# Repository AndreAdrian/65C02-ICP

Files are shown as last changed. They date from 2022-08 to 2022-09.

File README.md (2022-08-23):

# 65C02-ICP
65C02 single board computer with in-circuit-programming

The 65C02-ICP is my little 65C02 computer. I have 32kByte RAM, 8kByte EEPROM, a (buggy) WDC 65C51N ACIA RS232 interface and 7.3728MHz clock. Like [Ben Eater](https://eater.net/6502) I use a single 74HC00 for glue logic. And I have in-circuit-programming. This is the big difference to other 6502 single board computers. I need no EEPROM programmer. I have two CP2102 USB-to-UART bridges. One I use to program the EEPROM in-circuit, the other I use to communicate between my MS-Windows computer via [TeraTerm](https://ttssh2.osdn.jp/index.html.en) terminal emulator program and my 65C02 with 38400bps.

My monitor program - mon7.asm - uses RTS/CTS hardware handshake, interrupt driven receive and a 256 Byte receive buffer to work around the 65C51N TDRE (transmit data register empty) bug. I assume my monitor is compatible to other 6551. The monitor has three commands. Download bytes into memory with the : command, examine memory with the p command and execute a program with the r command. If the program executes a BRK opcode, the monitor prints a trace. That is the contents of the Y, X, A, P registers and the PC plus two more bytes on the stack. The monitor machine code length is 320Bytes. The mon7 api is:
```
monbyte = $0    ; 1 byte used by getbyte/putbyte
monword = $1    ; 2 bytes used by getword/putword
monwrptr= $3    ; 2 bytes buf write pointer used by getc
monrdptr= $5    ; 2 bytes buf read pointer used by getc
monbfcnt= $7    ; 1 byte buf count used by getc
montmpy = $8    ; 1 byte tmp used by getc
nmihook = $7EFD ; 3 bytes used by mon
monbuf  = $7F00 ; 256 bytes buf used by getc
getc    = $FF7E ; jsr console (65C51) input, out: a=char
echoc   = $FF81 ; jsr console input with echo, out: a=char
putc    = $FF84 ; jsr console output, in: a=char
asc2hex = $FF96 ; jsr convert ASCII to hex, in: a=ascii, out: a=hex
hex2asc = $FFA6 ; jsr convert hex to ASCII, in: a=hex, return a=ascii
getbyte = $FFB0 ; jsr input 2 Hex digits in ASCII, out: a=byte
putbyte = $FFC5 ; jsr output 2 Hex digits as ASCII, in: a=byte
getword = $FFDB ; jsr input 4 Hex digits in ASCII, out: monword=word
putword = $FFE6 ; jsr output 4 Hex digits as ASCII, in: monword=word
putcrlf = $FFF0 ; jsr output Carrige Return, Line Feed
```
The second program is int.asm. This is a 16Bit integer package with some basic ASCIIZ string subroutines. For subroutine arguments (parameters) I use register A=low byte, X=high byte. Or you can place the parameters into "well known" zero page variables and call the subroutines. The 16Bit integer package is fast. I use the fastest multiplication and division subroutines from the net and I use my own fast integer to decimal conversation subroutine. The same int2dec idea I used in the 1980s for my Z80 32Bit integer package. The int api is:
```
intsign = $9   ; 1 byte used by dec2int, intdiv, i32div
intarg  = $A   ; 2 bytes 16bit argument
intacc  = $C   ; 4 bytes 32bit accumulator (mul, div need 32bit)
getsa   = $FCC0 ; in: console, out: x=high, a=low ASCII pointer len<256
gets    = $FCC4 ; in: console, out: strptr ASCIIZ pointer len<256
putsa   = $FCD5 ; in: x=high, a=low ASCIIZ pointer len<256, out: console
puts    = $FCD9 ; in: strptr ASCIIZ pointer len<256, out: console
dec2inta= $FCE6 ; signed/unsigned decimal ASCII to 16bit signed/unsigned in: x=high, a=low ASCII ptr len<256, out: intacc
dec2int = $FCEA ; in: strptr ASCIIZ pointer len<256, out: intacc
int2deca= $FD2B ; signed 16bit to signed decimal ASCII in: intacc, out: x=high, a=low ASCIIZ ptr len<256
int2dec = $FD2F ; in: intacc, out: strptr ASCIIZ pointer len<256
uns2deca= $FD42 ; unsigned 16bit to unsigned decimal ASCII in: intacc, out: x=high, a=low ASCIIZ ptr len<256
uns2dec = $FD46 ; in: intacc out: strptr ASCIIZ pointer len<256
intmula = $FDEB ; signed multiplication in: x=high, a=low value, intarg, out: 32bit (intacc, resulth)
unsmula = $FDEB ; unsigned multiplication in: x=high, a=low value, intarg, out: 32bit (intacc, resulth)
intmul  = $FDEF ; in: intacc, intarg out: 32bit (intacc, resulth)
unsmul  = $FDEF ; in: intacc, intarg out: 32bit (intacc, resulth)
intdiva = $FE49 ; signed division 16bit/16bit in: x=high, a=low value, intarg, out: intacc=acc/arg, remaindr=acc%arg
intdiv  = $FE4D ; in: intacc, intarg, out: intacc=acc/arg, remaindr=acc%arg
i32div  = $FE6C ; signed division 32bit/16bit in: 32bit (intacc, remaindr), intarg, out: intacc=acc/arg, remaindr=acc%arg
unsdiva = $FE86 ; unsigned division 16bit/16bit in: x=high, a=low value, intarg, out: intacc=acc/arg, remaindr=acc%arg
unsdiv  = $FE8A ; in: intacc, intarg, out: intacc=acc/arg, remaindr=acc%arg
u32div  = $FE90 ; unsigned division 32bit/16bit in: 32bit (intacc, remaindr), intarg, out: intacc=acc/arg, remaindr=acc%arg
```
The int machine code length is 512Bytes. There are no addition or subtraction subroutines. You write these better
as inline. My int package can do scaling operation. That is a multiplication followed by a division
with a 32Bit intermediate result. The Forth programming language has the scaling command */.

Last but not least is int_t.asm, a test program for the int package. You normally execute int_t in RAM. Just drop the assembler output with ALT-V into the TeraTerm window and mon7 will store the bytes into RAM. A typical output of the int_t program is:
```
\0800: A9 0C A2 0A 20 D5 FC A9
\0808: 04 A2 02 20 C0 FC A9 AD
... many more lines
\0BA8: 65 6C 20 52 3A 20 52 65
\0BB0: 73 75 6C 74 3A 20 00
\0800r

puts: int version 20220823
65C02 wisdom of the day:
RAM needs the phi0 clock,
65C51 needs the phi2 clock
and the EEPROM does not care.
gets: Enter text: Hello 65C02-ICP
gets: Your text: Hello 65C02-ICP
int2dec: $8000 -32768
int2dec: $0000 0
int2dec: $7530 30000
int2dec: $FFFF -1
uns2dec: $8000 32768
uns2dec: $FFFF 65535
dec2int: Enter number: -123
int2dec: Your number: -123
dec2int: Enter number: -123
uns2dec: Your number: 65413
intmul: Enter number: 300
intmul: Enter number: -100
intmul: Result: $012B8AD0 -30000
intdiv: Enter number: 30000
intdiv: Enter number: 17
intdiv: Result: 1764 12
R parallel R: Enter number: 32767
R parallel R: Enter number: 32768
R parallel R: Result: 16383

! 05 F9 0A 31 9F 09 FF 7F
```
The first lines show the machine code download. I use the hex format that the [virtual 6502 assembler](https://www.masswerk.at/6502/assembler.html) produces. The 0800r command starts program execution at RAM memory location $0800 (800 hexadecimal). The program ends in a BRK. The trace output starts with a !.

The R parallel R test section uses the scaling operation. Without it, the maximum numbers are 255 and 256.

I draw the 65C02-ICP schematics with KiCad. At the moment there is only a breadboard build. The main components are:
- 7.3728MHz or 1.8432MHz clock oscillator
- W65C02 14MHz CPU
- W65C51N 14 MHz ACIA
- 28C64 8KByte EEPROM
- 62C256 32KByte static RAM
- 74HC00 glue logic
- 74HCT04, 74HC123, 3 x 74HC595 for in-circuit-programming
- 2 x CP2102 modules for USB connection

The in-circuit-programming part needs some hardware on the target computer - the 65C02 - and some software on the MS-Windows development computer. The EEPROM programmer software - named usb.exe - is in directory usb. There are the minimum files to recreate a Visual Studio project. Before you start Visual Studio, you have to get some files from Silabs, the CP2102 manufacturer. You need files SiUSBXp.h and SiUSBXp.lib in directoty usb/usb and file SiUSBXp.dll in directory usb/x64/Release. You find these files in the [USBXpress SDK v6.7.4 11/24/2021](https://www.silabs.com/developers/direct-access-drivers). You have to compile "Release" version, not "Debug" version, because the Silabs files need this. Again I use the machine code or object code format of virtual 6502 assembler. I copy the object code from virtual 6502 assembler to a hex file, e.g. mon7.hex for the monitor program. Then I call the EEPROM programmer program:
```
C:\src\usb\usb\x64\Release>usb mon7.hex
CP2102 EEPROMer
usage: usb [[filename] singlestep]
USBX Devices found = 1
USBX Device = 0 name = 0001
prog time = 5360 ms
```
The programmer needs 5 seconds to program 320bytes. This is slow, but hey, what to you expect from my low-cost hardware solution? How does the programmer work? I use only two RS232 symbols. One symbol is all zeros, the other is all ones. The 74HC123 monoflop produces out of the RS232 start bit a rising edge at data bit 3 location. At that time the RS232 signal is either 0 or 1. I use this rising edge as SPI clock signal SCK and the RS232 TxD signal from the CP2102 USB-to-UART bridge as SPI MOSI signal to shift 24 bits into 3 74HC595 shift registers. After the bits are "loaded", the USB-to-UART bridge uses a /DTR pulse to operate the EEPROM /WE pin. Because real-time performance of MS-Windows is poor, this pulse is 3ms (milliseconds) long - even if the CPU is 4GHz fast. The 24 bits set address bus A0 to A15 and data bus D0 to D7. While the in-circuit-programming hardware is active, the CPU is not active and vice versa. A simple on-off switch does the trick.

By the way, for EEPROM programming, the CP2102 has to work as USBXpress device. I use [CP210x Legacy Programming Utilities](https://community.silabs.com/s/article/cp210x-legacy-programming-utilities?language=en_US) program CP210xSetIDs to change the USB ProductID (PID) to 0xEA61. See [AN169 USBXpress Programmer's Guide](https://www.silabs.com/documents/public/application-notes/AN169.pdf) for details.

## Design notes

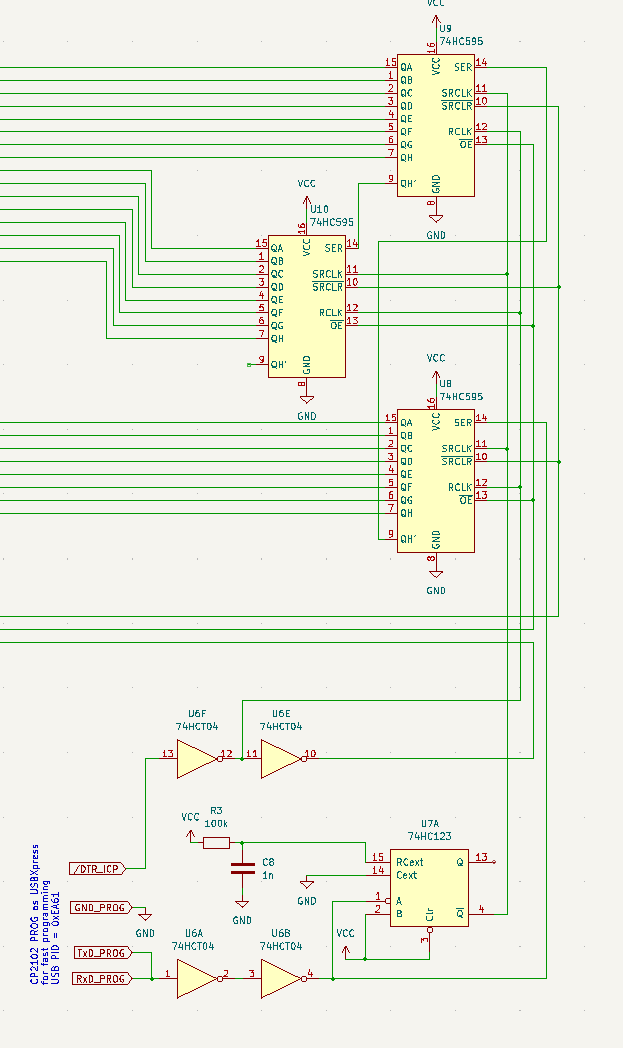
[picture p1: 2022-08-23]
65C02-ICP_part2.png

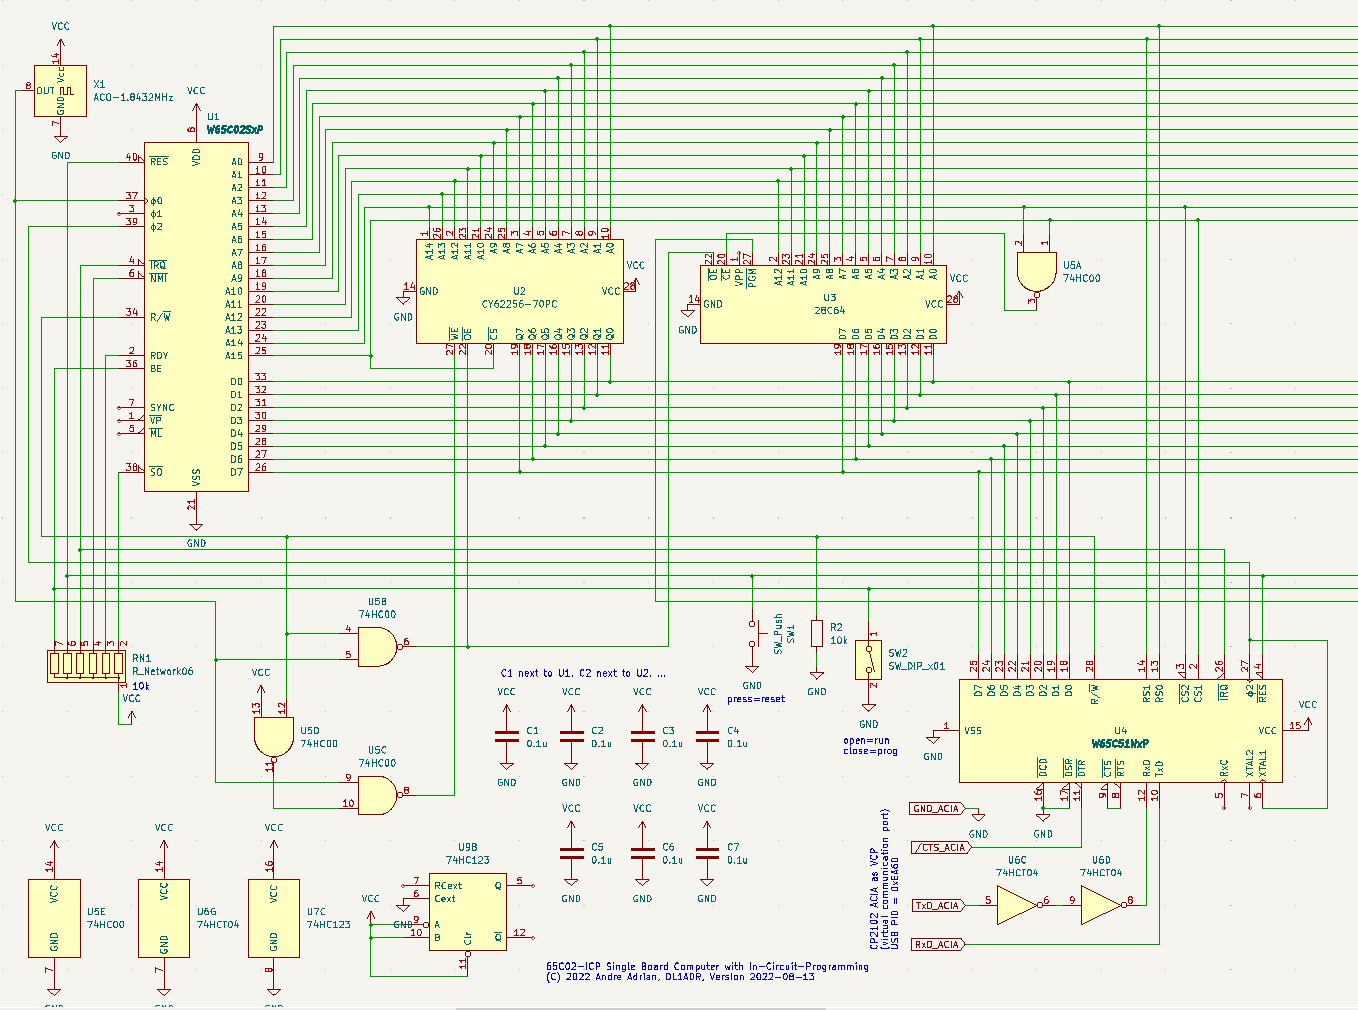
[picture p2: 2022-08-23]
65C02-ICP_part1.png

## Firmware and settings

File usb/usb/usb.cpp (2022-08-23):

/* usb.cpp
 * (in-circuit) EEPROM programmer with CP2102, version 2022-08-06
 * (C) 2022 Andre Adrian, DL1ADR
 * MS-Windows version using Silicon Labs USBXpress library, because it is faster then VCP
 *
 * 2022-08-06 adr: first version
 * 2022-08-11 adr: main() sscanf_s() better assert message (for now)
 * 
 * The CP2102 USB-UART bridge pins TxD and /DTR are used to create SPI SCLK, SPI MOSI and 
 * EEPROM write strobe signals for the EEPROM programmer.
 * A RS232 symbol has one startbit, 8 databits and one stopbit. As databits values we only
 * use 0x00 and 0xff. Without a RS232 symbol, the CP2102 TxD line is logic 1 (high). 
 * A 0x00 value gives a long logic 0 pulse, a 0xff value gives a short logic 0 pulse.
 * A 74HC123 monoflop differentiates the RS232 symbols into MOSI bits 0 or 1.
 * The falling edge on the /TxD line triggers the monoflop and value sampling happens
 * after 5 bit-times, that is after 43 microseconds for 115200 bps (baud).
 * The /Q monoflop output is used as SPI SCLK. The TxD line is used as SPI MOSI.
 * Three 74HC595 serial-in, parallel-out shift registers provide 24 parallel outputs
 * for the EEPROM address and data pins. The CP2102 /DTR connects to the EEPROM /WE
 * pin. For programming, the EEPROM /CE pin is 0 and the /OE pin is 1.
 * 
 * The /DTR strobe is 3 milliseconds. The EEPROM datasheet specifies a minimum write
 * pulse width of 100 nanoseconds. The length of /DTR strobe is the weak point of this
 * EEPROM programmer.
 * 
 * The CP2102 pins TxD and /RxD are connected. The host computer can read back the
 * transmitted RS232 symbols. This is necessary because SI_Write() is asynchrounous.
 * The call returns before the bytes are transfered "on the wire".
 * 
 * The EEPROM programmer hardware is low-cost: CP2102, 74HCT04, 74HC123, 74HC595. It brings
 * in-circuit-programming to 65C02 or Z80 systems. These CPUs have tri-state outputs
 * and the 74HC595 has tri-state outputs, too. A simple switch selects between run
 * and program mode.
 * 
 * Note: Use the Silabs program CP210xSetIDs.exe to set CP2102 product ID from 0xEA60 to 0xEA61
 * to make it a USBXpress device.
 * see https://community.silabs.com/s/article/cp210x-legacy-programming-utilities?language=en_US
 */

#include <stdio.h>
#undef NDEBUG           // Release needs this for active assert
#include <assert.h>
#include <Windows.h>
#include "SiUSBXp.h"


enum {
    SI_BAUD_921600 = 921600,
    SI_BAUD_460800 = 460800,
    SI_BAUD_230400 = 230400,
    SI_BAUD_115200 = 115200,
    SI_BAUD_76800 = 76800,
    SI_BAUD_57600 = 57600,
    SI_BAUD_38400 = 38400,
    SI_BAUD_19200 = 19200,
    SI_BAUD_9600 = 9600,
    SI_DATABITS_5 = 5,
    SI_DATABITS_6 = 6,
    SI_DATABITS_7 = 7,
    SI_DATABITS_8 = 8,
    SI_STOPBITS_1 = 0,
    SI_STOPBITS_2 = 2,
    SI_PARITY_NONE = 0, 
    SI_PARITY_ODD = 1,
    SI_PARITY_EVEN = 2,
    SI_PARITY_MARK = 3,
    SI_PARITY_SPACE = 4,
    L = 0,
    H = 0xff,

    // program configuration
    SI_BAUD = SI_BAUD_115200,
    SI_STOPBITS = SI_STOPBITS_1,
    SI_DATABITS = SI_DATABITS_8,
    SI_PARITY = SI_PARITY_NONE,
};

void prog(HANDLE handle, char* buf, int len, int singlestep)
{
    // write SPI bits as long/short RS232 symbols
    DWORD bytes;
    SI_STATUS status = SI_Write(handle, buf, len, &bytes, NULL);
    assert(SI_SUCCESS == status && len == bytes && "SI_Write");

    // use read back to ensure that bits are correctly transfered
    char rdbuf[24];
    DWORD rdbytes;
    status = SI_Read(handle, rdbuf, len, &rdbytes, NULL);
    assert(SI_SUCCESS == status && "SI_Read1");
    assert(len == rdbytes && "SI_Read2");
    assert(0 == memcmp(buf, rdbuf, sizeof rdbuf) && "SI_Read3");

    // toggle /WE = /DTR low and high again.
    // /DTR is low for 3 milliseconds.
    status = SI_SetFlowControl(handle, SI_STATUS_INPUT, SI_HELD_INACTIVE, SI_HELD_ACTIVE,
        SI_STATUS_INPUT, SI_STATUS_INPUT, 0);
    assert(SI_SUCCESS == status && "SI_SetFlowControl");
    status = SI_SetFlowControl(handle, SI_STATUS_INPUT, SI_HELD_INACTIVE, SI_HELD_INACTIVE,
        SI_STATUS_INPUT, SI_STATUS_INPUT, 0);
    assert(SI_SUCCESS == status && "SI_SetFlowControl");

    // after /WE the EEPROM needs "Write Cycle Time" of 1ms for internal programming
    Sleep(1);

    if (singlestep) {
        for (int j = 0; j < len; ++j) {
            if (buf[j]) putchar('1');
            else putchar('0');
            if (7 == j || 15 == j) putchar(' ');
        }
        putchar('\n');
        fflush(stdout);
        getchar();
    }
}

int main(int argc, char *argv[])
{
    printf("CP2102 EEPROMer\n");
    printf("usage: usb [[filename] singlestep]\n");
    fflush(stdout);

    FILE* fp = NULL;
    if (argc >= 2) {
        errno_t rv = fopen_s(&fp, argv[1], "rb");
        assert(0 == rv && "fopen_s");
    }
    int singlestep = 0;
    if (argc >= 3) {
        singlestep = 1;
    }

    DWORD devices;
    SI_STATUS status = SI_GetNumDevices(&devices);
    assert (SI_SUCCESS == status && "SI_GetNumDevices");

    printf("USBX Devices found = %ld\n", devices);

    for (DWORD i = 0; i < devices; ++i) {
        SI_DEVICE_STRING    name;
        status = SI_GetProductString(i, name, SI_RETURN_SERIAL_NUMBER);
        assert(SI_SUCCESS == status && "SI_GetProductString");

        printf("USBX Device = %ld name = %s\n", i, name);
    }
    fflush(stdout);

    HANDLE handle;
    status = SI_Open(0, &handle);
    assert(SI_SUCCESS == status && "SI_Open");

    status = SI_SetBaudRate(handle, SI_BAUD);
    assert(SI_SUCCESS == status && "SI_SetBaudRate");

    status = SI_SetLineControl(handle, SI_STOPBITS | (SI_PARITY << 4) | (SI_DATABITS << 8));
    assert(SI_SUCCESS == status && "SI_SetLineControl");

    // write strobe = /DTR to high
    status = SI_SetFlowControl(handle, SI_STATUS_INPUT, SI_HELD_INACTIVE, SI_HELD_INACTIVE,
        SI_STATUS_INPUT, SI_STATUS_INPUT, 0);
    assert(SI_SUCCESS == status && "SI_SetFlowControl");


    if (argc >= 2) {
        ULONGLONG t0 = GetTickCount64();
        char buf[128];
        while (fgets(buf, sizeof buf, fp)) {
#if 0
            printf("%s", buf);
            fflush(stdout);
#endif
            int a, d[8];
            int rv2 = sscanf_s(buf, "%x: %x %x %x %x %x %x %x %x", &a, &d[0], &d[1], &d[2], &d[3], &d[4], &d[5], &d[6], &d[7]);
            assert(9 == rv2 && "sscanf needs 8 data bytes");

            //printf("%04x: %02X %02X %02X %02X %02X %02X %02X %02X\n", a, d[0], d[1], d[2], d[3], d[4], d[5], d[6], d[7]);
            //fflush(stdout);

            for (int i = 0; i < 8; ++i, ++a) {
                char buf[24];
                memset(buf, 0, sizeof buf);     // init auf L
                for (int j = 0; j < 16; ++j) {
                    int mask = 1 << (15 - j);
                    if (a & mask) buf[j] = H;
                }
                for (int j = 0; j < 8; ++j) {
                    int mask = 1 << (7 - j);
                    if (d[i] & mask) buf[16 + j] = H;
                }
                prog(handle, buf, sizeof buf, singlestep);
            }
            // putchar('\n');
        }
        ULONGLONG t1 = GetTickCount64();
        printf("prog time = %llu ms\n", t1 - t0);
        fflush(stdout);
    }
    else {
        char buf[24] = {
        //  A15/A7               A8/A0
        //  D0/Qa                D7/Qh
        //  15 1  2  3  4  5  6  7
            L, H, L, H, L, H, L, H,     // U10
            L, L, H, H, L, L, H, H,     // U9
            L, L, L, L, H, H, H, H};    // U8
        for (;;) {
            prog(handle, buf, sizeof buf, 0);
        }
#if 0
        char buf2[24] = {
        //  D0/Qa                D7/Qh
        //  15 1  2  3  4  5  6  7
            H, L, H, L, H, L, H, L,     // U10
            H, H, L, L, H, H, L, L,     // U9
            H, H, H, H, L, L, L, L};    // U8
        for (;;) {
            prog(handle, buf2, sizeof buf2, 0);
        }
#endif
    }

    status = SI_Close(handle);
    assert(SI_SUCCESS == status && "SI_Close");

    if (argc >= 2) {
        fclose(fp);
    }
    return 0;
}

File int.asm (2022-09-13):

; int.asm
; 6502 16bit signed, unsigned integer package with 32bit */ scaling operator
; machine code size 512bytes
; (C) 2022 Andre Adrian
; Assembler:
; https://www.masswerk.at/6502/assembler.html

; 2022-08-02 first version
; 2022-08-08 add divide
; 2022-08-12 add puts
; 2022-08-15 for mon7
; 2022-08-16 add uns2dec
; 2022-08-17 add intdiv, int2dec
; 2022-08-18 add dec2int
; 2022-08-19 add gets
; 2022-08-23 no gap between mon zp and int zp variables
; 2022-09-12 faster mul

; import mon7 9600bps/38400bps, RTS/CTS, 256bytes rx buf
  monbyte = $0    ; 1 byte used by getbyte/putbyte
  monword = $1    ; 2 bytes used by getword/putword
  monwrptr= $3    ; 2 bytes buf write pointer used by getc
  monrdptr= $5    ; 2 bytes buf read pointer used by getc
  monbfcnt= $7    ; 1 byte buf count used by getc
  montmpy = $8    ; 1 byte tmp used by getc
  nmihook = $7EFD ; 3 bytes used by mon
  monbuf  = $7F00 ; 256 bytes buf used by getc
  getc    = $FF7E ; jsr acia input, return a=char
  echoc   = $FF81 ; jsr acia input with echo, return a=char
  putc    = $FF84 ; jsr acia output, a=char
  asc2hex = $FF96 ; jsr convert ASCII to hex, a=ascii, return a=hex
  hex2asc = $FFA6 ; jsr convert hex to ASCII, a=hex, return a=ascii
  getbyte = $FFB0 ; jsr input 2 Hex digits in ASCII, return a=byte
  putbyte = $FFC5 ; jsr output 2 Hex digits as ASCII, a=byte
  getword = $FFDB ; jsr input 4 Hex digits in ASCII, return monword=word
  putword = $FFE6 ; jsr output 4 Hex digits as ASCII, monword=word
  putcrlf = $FFF0 ; jsr output Carrige Return, Line Feed

; mon aliases
  inttmpy = monbyte   ; 1 byte used by uns2dec
  strptr  = monword   ; 2 bytes used by puts, dec2int, int2dec, uns2dec

; int
  intsign = $9   ; 1 byte used by dec2int, intdiv, i32div
  intarg  = $A   ; 2 bytes 16bit argument
  intacc  = $C   ; 4 bytes 32bit accumulator (mul, div need 32bit)

; int aliases
  plier   = intacc    ; in multiplier
  plicand = intarg    ; in multiplicand
  dividend= intacc    ; in (denominator)
  divisor = intarg    ; in (numerator)
  result  = intacc    ; out low(plier * plicand) = dividend / divisor
  resulth = intacc+2  ; out high(plier * plicand)
  remaindr= intacc+2  ; out dividend % divisor

; const
  NUL = 0     ; ASCIIZ terminal char
  LF  = $0A   ; ASCII line feed
  CR  = $0D   ; ASCII carrige return
  SPC = $20   ; ASCII space

; Program im ROM
  .org $fcc0  ; 512 bytes below monitor $fec0

; ************************************
; int.asm implementation (512bytes)

; subroutine naming:
; puts, gets = console output ASCIIZ string, console input ASCIIZ string
; dec2int = ASCIIZ decimal to signed or unsigned 16bit
; int2dec, uns2dec = signed 16bit to ASCIIZ decimal, unsigned 16bit to ASCIIZ decimal
; the following subroutines are written type (int, uns, i32, u32) operation (mul, div)
; and optional argument passing (a) like intdiva
; int, uns, i32, u32 = signed 16bit, unsigned 16bit, signed 32bit, unsigned 32bit
; mul, div = multiplication, division (do addition, subtraction inline)
; optional a = use register a, x for low byte, high byte argument

getsa:
; in: console, out: x=high, a=low ASCII pointer len<256
  sta strptr
  stx strptr+1

gets:
; in: console, out: strptr ASCIIZ pointer len<256
  ldy #0
: jsr echoc
  sta (strptr),y
  iny
  cmp #SPC
  bcc :+
  bcs :-
: jmp uns2dece    ; append NUL

putsa:
; in: x=high, a=low ASCIIZ pointer len<256, out: console
  sta strptr
  stx strptr+1

puts:
; in: strptr ASCIIZ pointer len<256, out: console
  ldy #0
: lda (strptr),y
  beq :+
  jsr putc
  iny
  bne :-     ; bra
: rts

dec2inta:
; signed/unsigned decimal ASCII to 16bit signed/unsigned
; ASCII number is terminated by char<'0' like SPC, CR, LF
; in: x=high, a=low ASCII pointer len<256, out: intacc
  sta strptr
  stx strptr+1

dec2int:
; signed/unsigned decimal ASCII to 16bit signed/unsigned
; ASCII number is terminated by char<'0' like SPC, CR, LF
; in: strptr ASCIIZ pointer len<256, out: intacc
  ldy #0
  sty intsign
  sty intacc
  sty intacc+1
  lda (strptr),y
  cmp #'-
  bne :+
  lda #$80
  sta intsign
  jsr strptrpp
: lda (strptr),y
  iny
  sec             ; ASCII code to digit value
  sbc #'0
  bcc :+          ; if a<'0 then return
  pha
  jsr intm10      ; shift decimal left
  pla
  clc             ; add as last digit
  adc intacc
  sta intacc
  bcc :-
  inc intacc+1
  bcc :-          ; bra
: lda intsign
  bpl :+
  jsr intaccng
: rts

strptrpp:
; strptr++
  clc
  lda strptr
  adc #1          ; note inc does not set carry
  sta strptr
  bcc :-          ; if result<$100 then skip
  inc strptr+1
: rts

int2deca:
; signed 16bit to signed decimal ASCII
; in: intacc, out: x=high, a=low ASCIIZ pointer len<256
  sta strptr
  stx strptr+1

int2dec:
; signed 16bit to signed decimal ASCII
; in: intacc, out: strptr ASCIIZ pointer len<256
  lda intacc+1
  bpl :+
  jsr intaccng
  ldy #0
  lda #'-
  sta (strptr),y
  jsr strptrpp
: jmp uns2dec

uns2deca:
; unsigned 16bit to unsigned decimal ASCII
; in: intacc, out: x=high, a=low ASCIIZ pointer len<256
  sta strptr
  stx strptr+1

uns2dec:
; unsigned 16bit to unsigned decimal ASCII
; in: intacc out: strptr ASCIIZ pointer len<256
  lda #0
  sta inttmpy     ; 2nd y
  ldy #'0         ; do 10000s
: sec             ; provisional sub
  lda intacc
  sbc #<10000
  tax             ; store low sub result to tmp
  lda intacc+1
  sbc #>10000
  bcc :+          ; if intacc<10000 then ignore sub result
  stx intacc      ; else store sub result permanent
  sta intacc+1
  iny             ; the "remainder"
  bne :-          ; bra
: jsr uns2dech
  ldy #'0         ; do 1000s
: sec
  lda intacc
  sbc #<1000
  tax
  lda intacc+1
  sbc #>1000
  bcc :+
  stx intacc
  sta intacc+1
  iny
  bne :-
: jsr uns2dech
  ldy #'0         ; do 100s
: sec
  lda intacc
  sbc #<100
  tax
  lda intacc+1
  sbc #>100
  bcc :+
  stx intacc
  sta intacc+1
  iny
  bne :-
: jsr uns2dech
  ldy #'0         ; do 10s
: sec
  lda intacc
  sbc #<10
  tax
  lda intacc+1
  sbc #>10
  bcc :+
  stx intacc
  sta intacc+1
  iny
  bne :-
: jsr uns2dech
  clc             ; do 1s
  lda intacc
  adc #'0
  ldy inttmpy
  sta (strptr),y
  iny
uns2dece:
  lda #NUL        ; append NUL
  sta (strptr),y
  rts

uns2dech:
; private
; print without leading zeros, but with trailing zeros (tricky)
  tya
  ldy inttmpy
  bne :+          ; if not first char, skip no leading '0's test
  cmp #'0
  beq :++         ; no leading '0's test
: sta (strptr),y
  inc inttmpy
: rts

intm10:
unsm10:
; signed/unsigned integer multiply const 10
; in: intacc, out: intacc *= 10
  lda intacc      ; intacc *= 2
  asl
  sta intacc
  sta intarg      ; intarg = intacc
  lda intacc+1
  rol
  sta intacc+1
  sta intarg+1
  asl intacc      ; intacc *= 4
  rol intacc+1
  asl intacc
  rol intacc+1

intadd:
unsadd:
; signed/unsigned integer add
; in: intacc, intarg
; out: intacc += intarg
  clc
  lda intacc
  adc intarg
  sta intacc
  lda intacc+1
  adc intarg+1
  sta intacc+1
  rts
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
